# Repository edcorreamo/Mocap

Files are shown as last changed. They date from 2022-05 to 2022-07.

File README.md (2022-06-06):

## [ Esquemáticos ](https://github.com/edcorreamo/Mocap/tree/main/Esquematico)

En la presente sección va a encontrar el esquemático que se desarrollo para este proyecto ylas diferentes subsecciones que permiten conformar el circuito.

## [ Código ](https://github.com/JamesD004/MoCapUnal/tree/main/Imagenes)

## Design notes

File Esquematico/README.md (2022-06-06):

# Esquemático

## Esquema temporal

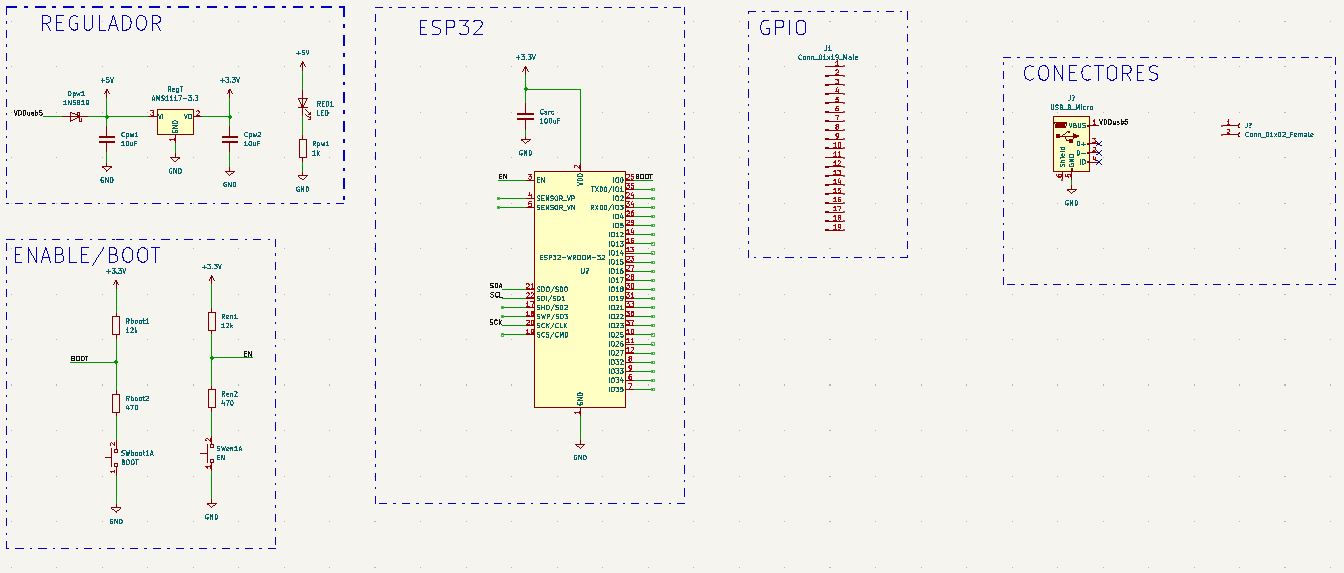
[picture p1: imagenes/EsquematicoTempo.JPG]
width=100


## Regulador
En esta seccion se encuentra el regulador de tensión buscando obtener una salida de 3.3V, para este proposito se hizo uso del regulador AMS1117. Por otro lado se implemento un diodo LED que ayuda a verificar el momento en el que el circuito se energice, el diodo schottky 1N5819 nos ayuda a asegurar que la tensión que pase por el regulador en la entrada V1 no se devuelva a la tension de entrada USB, finalmente los condensadores... . 

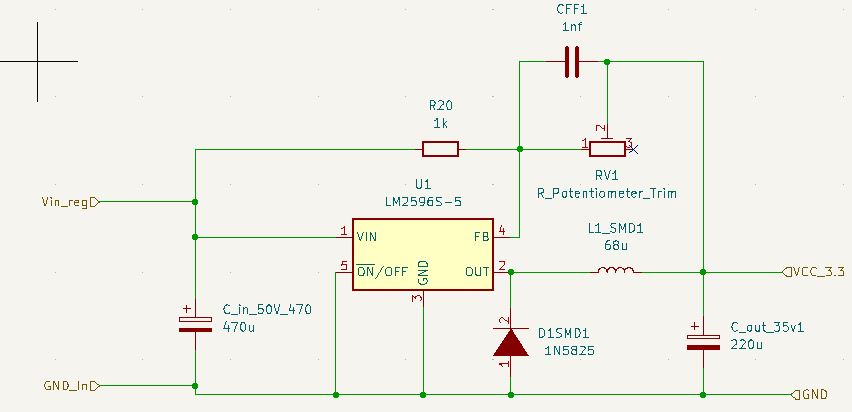
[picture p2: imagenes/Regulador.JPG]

A la salida del regulador se conecto un led que nos indica cuando el circuito se encuentre energizado, ya que la tensión de un led es de 1,6V y su corriente de peración es de 5mA la resistencia necesaria para su funcionamiento es de 330.

### LTspice
Con ayuda del IDE de LTspice diseñamos un pequeño cicuito y de este modo analizar la salida que se espera tener en este sistema, para este se usa un regulador LM317 con el cual se espera obtener un comportamiento similar con el AMS1117.

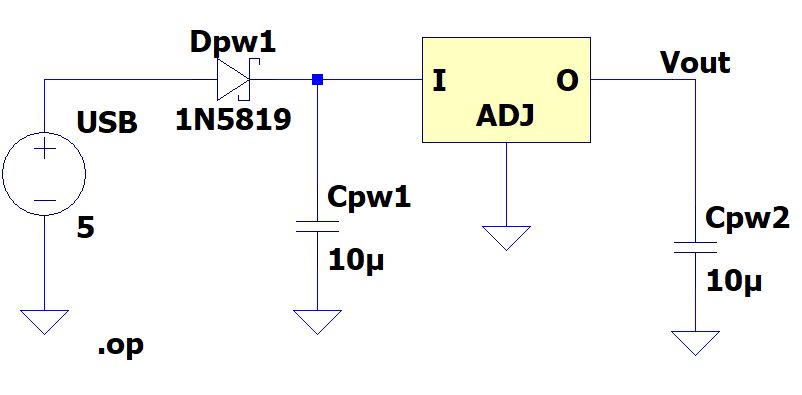
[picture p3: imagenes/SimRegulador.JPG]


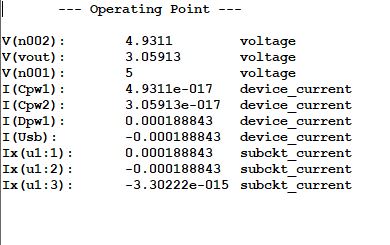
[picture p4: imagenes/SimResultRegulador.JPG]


## ENABLE/BOOT
La tensión en el enable y el boot en un caso ideal se considera con valores de 0 y 1, sin embargo esta se encuentra en un umbral de funcionamiento, en donde el valor de cero puede tomar hasta un valor de 0.124 mientras que para el funcionamiento del enable se tomo desde un valor de 0.7 el cual se va representar con ayuda de un diodo led.
### Ltspice
La tensión de caida de un diodo esta dado por 0.7V y la corriente en el led es de 5mA, por otro lado la corriente en el enable del ESP32 es de 264uA.
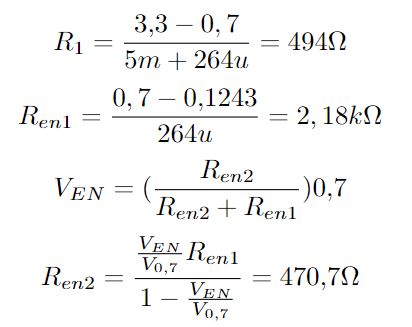
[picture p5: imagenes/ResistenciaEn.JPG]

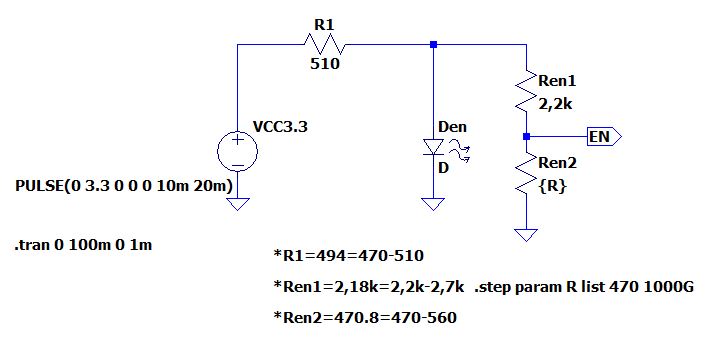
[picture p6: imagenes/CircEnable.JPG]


## ESP32


Para el desarrollo de este proyecto se hizo uso de un Soc ESP32-WROOM, debido a que representa una solucion ideal para suplir las necesidades de este proyecto. El Soc ESP32-WROOM entre otras cosas, posee un chip capaz de controlar multiplez sensores a la vez por medio de software y ademas cuenta tanto con modulo bluetooth como WIFI integrados, perimitiendo de esta manera la conxion inalambrica con otros dispositivos sin necesidad de un modulo complementario. 

Ahora, el proyecto se realizo teniendo en cuenta las condiciones de operacion y las limitaciones del ESP32-WROOM, este dispositivo debe ser alimentado idealmente con un voltaje de 3,3V o como maximo con un voltaje de 3,6V y puede entregar por sus pines de salida una corriente maxima de 1200mA. Ahora con respecto a sus diferesntes pines, la imagen anterior ilustra cada uno d ellos y sus particularidades.    

## Conectores

## USB

## MPU

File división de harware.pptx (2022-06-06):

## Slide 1

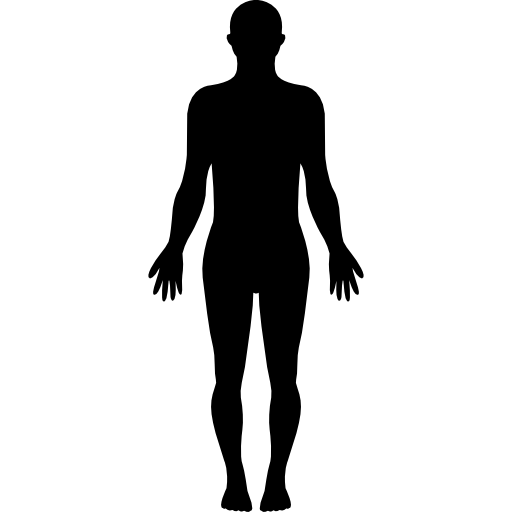
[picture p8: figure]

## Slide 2

1 sensor (sin bus)

1 bus + 1 sensor (pecho)

1 bus + 1 sensor bus

2 bus

2 bus (uno de ellos unido internamente al brazo)

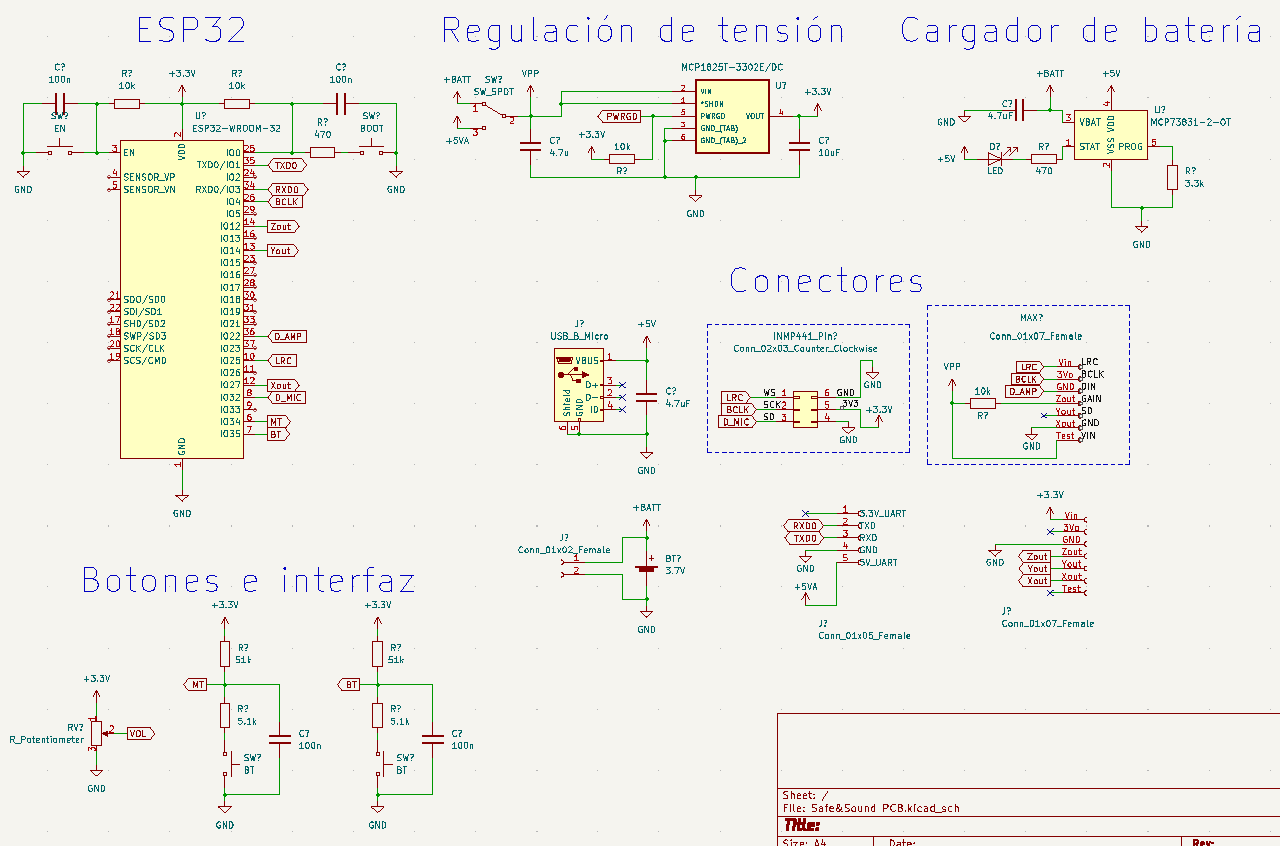
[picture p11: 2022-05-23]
copia de companeros.png

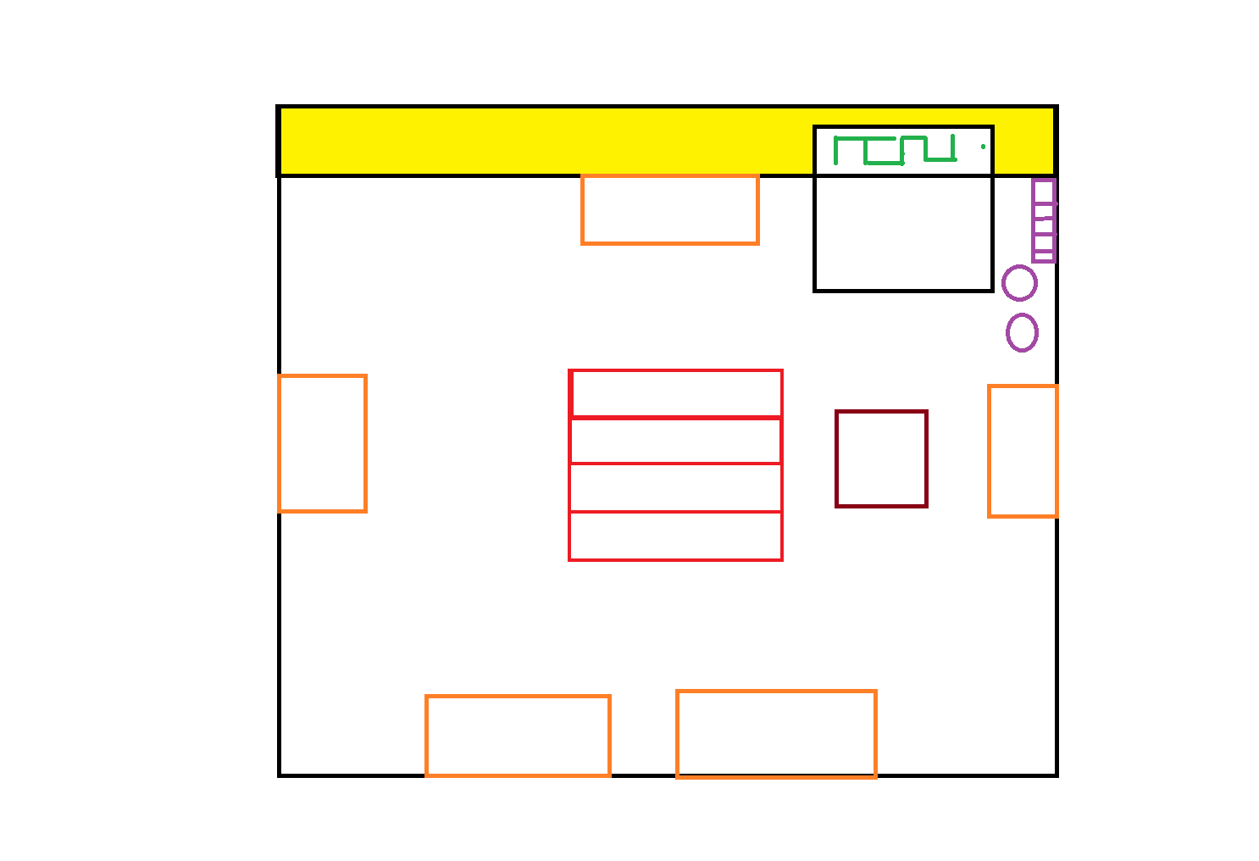
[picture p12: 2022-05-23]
posible ruteo.png

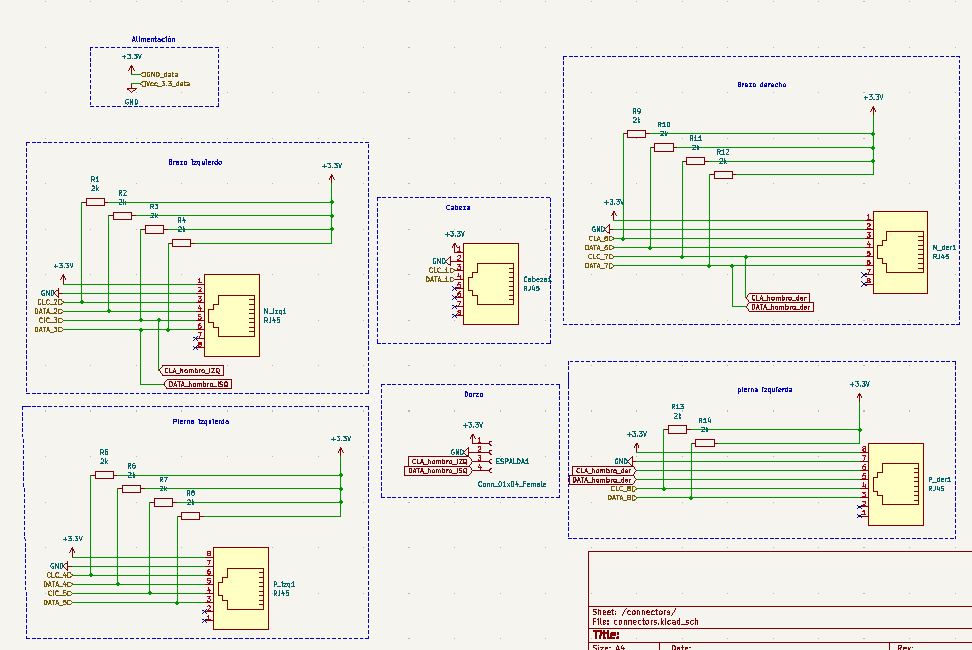
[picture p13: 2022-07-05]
imagenes/Conexiones.JPG

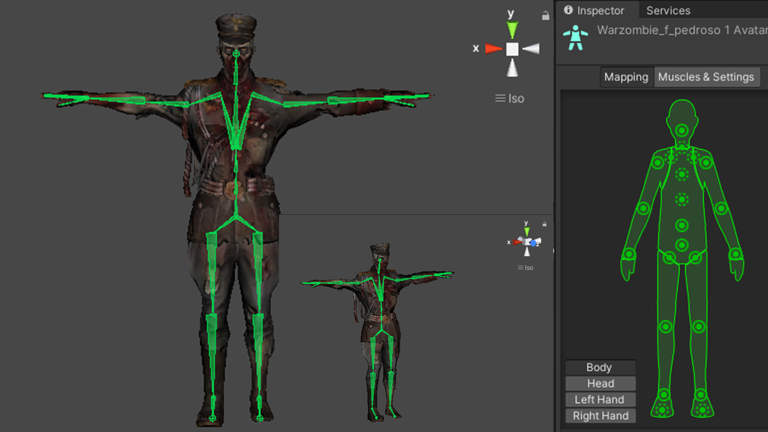
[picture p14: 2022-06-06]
imagenes/entornos_virtuales_2.png

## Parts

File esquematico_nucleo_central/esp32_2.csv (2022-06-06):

Source: | C:\Users\Prometeo\Documents\GitHub\Mocap\esquematico_nucleo_central\esp32_2.kicad_sch
Date: | 6/6/2022 11:11:27 AM
Tool: | Eeschema (6.0.1)
Generator: | C:\Program Files\KiCad\6.0\bin\scripting\plugins/bom_csv_grouped_by_value.py
Component Count: | 34
Individual Components:
Item | Qty | Reference(s) | Value | LibPart | Footprint | Datasheet | compra
 |  | Boot/flash1 | SW_Push | Switch:SW_Push | Button_Switch_SMD:SW_SPST_EVQQ2 | ~
 |  | C1 | 10u | Device:C | Capacitor_SMD:C_0805_2012Metric_Pad1.18x1.45mm_HandSolder | ~
 |  | C2 | 1nF/50V | Device:C | Capacitor_SMD:C_0805_2012Metric_Pad1.18x1.45mm_HandSolder | ~
 |  | C3 | 1nF/50V | Device:C | Capacitor_SMD:C_0805_2012Metric_Pad1.18x1.45mm_HandSolder | ~
 |  | C4 | 100u | Device:C | Capacitor_SMD:C_0805_2012Metric_Pad1.18x1.45mm_HandSolder | ~
 |  | C_in_50V_470 | 470u | Device:C_Polarized | Capacitor_SMD:CP_Elec_8x6.9 | ~
 |  | C_out_35v1 | 220u | Device:C_Polarized | Capacitor_SMD:CP_Elec_8x6.9 | ~
 |  | Cabeza1 | RJ45 | Connector:RJ45 | Connector_RJ:RJ45_Amphenol_54602-x08_Horizontal | ~
 |  | CFF1 | 1nf | Device:C | Capacitor_SMD:C_0805_2012Metric_Pad1.18x1.45mm_HandSolder | ~
 |  | Control_voltaje1 | Conn_01x02_Male | Connector:Conn_01x02_Male | Connector_PinHeader_2.54mm:PinHeader_1x02_P2.54mm_Vertical | ~
 |  | D1 | LED | Device:LED | LED_SMD:LED_1206_3216Metric_Pad1.42x1.75mm_HandSolder | ~
 |  | D1SMD1 | 1N5825 | pspice:DIODE | Diode_SMD:D_3220_8050Metric_Pad2.65x5.15mm_HandSolder | ~
 |  | D2 | LED | Device:LED | LED_SMD:LED_1206_3216Metric_Pad1.42x1.75mm_HandSolder | ~ | https://articulo.mercadolibre.com.co/MCO-638946948-diodo-led-smd-1206-x-5-unidades-_JM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
 |  | D3 | LED | Device:LED | LED_SMD:LED_1206_3216Metric_Pad1.42x1.75mm_HandSolder | ~ | https://articulo.mercadolibre.com.co/MCO-638946948-diodo-led-smd-1206-x-5-unidades-_JM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
 |  | ESP32 | ESP32-WROOM-32 | RF_Module:ESP32-WROOM-32 | RF_Module:ESP32-WROOM-32 | https://www.espressif.com/sites/default/files/documentation/esp32-wroom-32_datasheet_en.pdf
 |  | Espalda1 | Conn_01x08_Male | Connector:Conn_01x08_Male | Connector_PinHeader_2.54mm:PinHeader_1x08_P2.54mm_Vertical | ~
 |  | L1_SMD1 | 68u | Device:L | Inductor_SMD:L_Wuerth_HCM-1390 | ~
 |  | M_der1 | RJ45 | Connector:RJ45 | Connector_RJ:RJ45_Amphenol_54602-x08_Horizontal | ~
 |  | M_izq1 | RJ45 | Connector:RJ45 | Connector_RJ:RJ45_Amphenol_54602-x08_Horizontal | ~
 |  | N_batt1 | Conn_01x01_Female | Connector:Conn_01x01_Female | Connector_PinHeader_2.54mm:PinHeader_1x01_P2.54mm_Vertical | ~
 |  | P_Batt1 | Conn_01x01_Female | Connector:Conn_01x01_Female | Connector_PinHeader_2.54mm:PinHeader_1x01_P2.54mm_Vertical | ~
 |  | P_der1 | RJ45 | Connector:RJ45 | Connector_RJ:RJ45_Amphenol_54602-x08_Horizontal | ~
 |  | P_izq1 | RJ45 | Connector:RJ45 | Connector_RJ:RJ45_Amphenol_54602-x08_Horizontal | ~
 |  | Programador1 | Programador | Connector:Conn_01x05_Female | Connector_PinHeader_2.54mm:PinHeader_1x05_P2.54mm_Vertical | ~
 |  | R15 | 10k | Device:R | Resistor_SMD:R_0805_2012Metric_Pad1.20x1.40mm_HandSolder | ~
 |  | R16 | 10k | Device:R | Resistor_SMD:R_0805_2012Metric_Pad1.20x1.40mm_HandSolder | ~
 |  | R17 | 10k | Device:R | Resistor_SMD:R_0805_2012Metric_Pad1.20x1.40mm_HandSolder | ~
 |  | R18 | 10k | Device:R | Resistor_SMD:R_0805_2012Metric_Pad1.20x1.40mm_HandSolder | ~
 |  | R19 | 10k | Device:R | Resistor_SMD:R_0805_2012Metric_Pad1.20x1.40mm_HandSolder | ~
 |  | R20 | 1k | Device:R | Resistor_SMD:R_0805_2012Metric_Pad1.20x1.40mm_HandSolder | ~
 |  | Reset1 | SW_Push | Switch:SW_Push | Button_Switch_SMD:SW_SPST_EVQQ2 | ~
 |  | RV1 | R_Potentiometer_Trim | Device:R_Potentiometer_Trim | Potentiometer_THT:Potentiometer_Bourns_3296W_Vertical | ~
 |  | SW1 | SW_DIP_x01 | Switch:SW_DIP_x01 | Button_Switch_THT:SW_DIP_SPSTx01_Slide_9.78x4.72mm_W7.62mm_P2.54mm | ~
 |  | U1 | LM2596S-5 | Regulator_Switching:LM2596S-5 | Package_TO_SOT_SMD:TO-263-5_TabPin3 | http://www.ti.com/lit/ds/symlink/lm2596.pdf
Collated Components:
Item | Qty | Reference(s) | Value | LibPart | Footprint | Datasheet | compra
1 | 2 | Boot/flash1, Reset1 | SW_Push | Switch:SW_Push | Button_Switch_SMD:SW_SPST_EVQQ2 | ~
2 | 1 | C1 | 10u | Device:C | Capacitor_SMD:C_0805_2012Metric_Pad1.18x1.45mm_HandSolder | ~
3 | 2 | C2, C3 | 1nF/50V | Device:C | Capacitor_SMD:C_0805_2012Metric_Pad1.18x1.45mm_HandSolder | ~
4 | 1 | C4 | 100u | Device:C | Capacitor_SMD:C_0805_2012Metric_Pad1.18x1.45mm_HandSolder | ~
5 | 1 | C_in_50V_470 | 470u | Device:C_Polarized | Capacitor_SMD:CP_Elec_8x6.9 | ~
6 | 1 | C_out_35v1 | 220u | Device:C_Polarized | Capacitor_SMD:CP_Elec_8x6.9 | ~
7 | 5 | Cabeza1, M_der1, M_izq1, P_der1, P_izq1 | RJ45 | Connector:RJ45 | Connector_RJ:RJ45_Amphenol_54602-x08_Horizontal | ~
8 | 1 | CFF1 | 1nf | Device:C | Capacitor_SMD:C_0805_2012Metric_Pad1.18x1.45mm_HandSolder | ~
9 | 1 | Control_voltaje1 | Conn_01x02_Male | Connector:Conn_01x02_Male | Connector_PinHeader_2.54mm:PinHeader_1x02_P2.54mm_Vertical | ~
10 | 3 | D1, D2, D3 | LED | Device:LED | LED_SMD:LED_1206_3216Metric_Pad1.42x1.75mm_HandSolder | ~ | https://articulo.mercadolibre.com.co/MCO-638946948-diodo-led-smd-1206-x-5-unidades-_JM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
11 | 1 | D1SMD1 | 1N5825 | pspice:DIODE | Diode_SMD:D_3220_8050Metric_Pad2.65x5.15mm_HandSolder | ~
12 | 1 | ESP32 | ESP32-WROOM-32 | RF_Module:ESP32-WROOM-32 | RF_Module:ESP32-WROOM-32 | https://www.espressif.com/sites/default/files/documentation/esp32-wroom-32_datasheet_en.pdf
13 | 1 | Espalda1 | Conn_01x08_Male | Connector:Conn_01x08_Male | Connector_PinHeader_2.54mm:PinHeader_1x08_P2.54mm_Vertical | ~
14 | 1 | L1_SMD1 | 68u | Device:L | Inductor_SMD:L_Wuerth_HCM-1390 | ~
15 | 2 | N_batt1, P_Batt1 | Conn_01x01_Female | Connector:Conn_01x01_Female | Connector_PinHeader_2.54mm:PinHeader_1x01_P2.54mm_Vertical | ~
16 | 1 | Programador1 | Programador | Connector:Conn_01x05_Female | Connector_PinHeader_2.54mm:PinHeader_1x05_P2.54mm_Vertical | ~
17 | 5 | R15, R16, R17, R18, R19 | 10k | Device:R | Resistor_SMD:R_0805_2012Metric_Pad1.20x1.40mm_HandSolder | ~
18 | 1 | R20 | 1k | Device:R | Resistor_SMD:R_0805_2012Metric_Pad1.20x1.40mm_HandSolder | ~
19 | 1 | RV1 | R_Potentiometer_Trim | Device:R_Potentiometer_Trim | Potentiometer_THT:Potentiometer_Bourns_3296W_Vertical | ~
20 | 1 | SW1 | SW_DIP_x01 | Switch:SW_DIP_x01 | Button_Switch_THT:SW_DIP_SPSTx01_Slide_9.78x4.72mm_W7.62mm_P2.54mm | ~
21 | 1 | U1 | LM2596S-5 | Regulator_Switching:LM2596S-5 | Package_TO_SOT_SMD:TO-263-5_TabPin3 | http://www.ti.com/lit/ds/symlink/lm2596.pdf

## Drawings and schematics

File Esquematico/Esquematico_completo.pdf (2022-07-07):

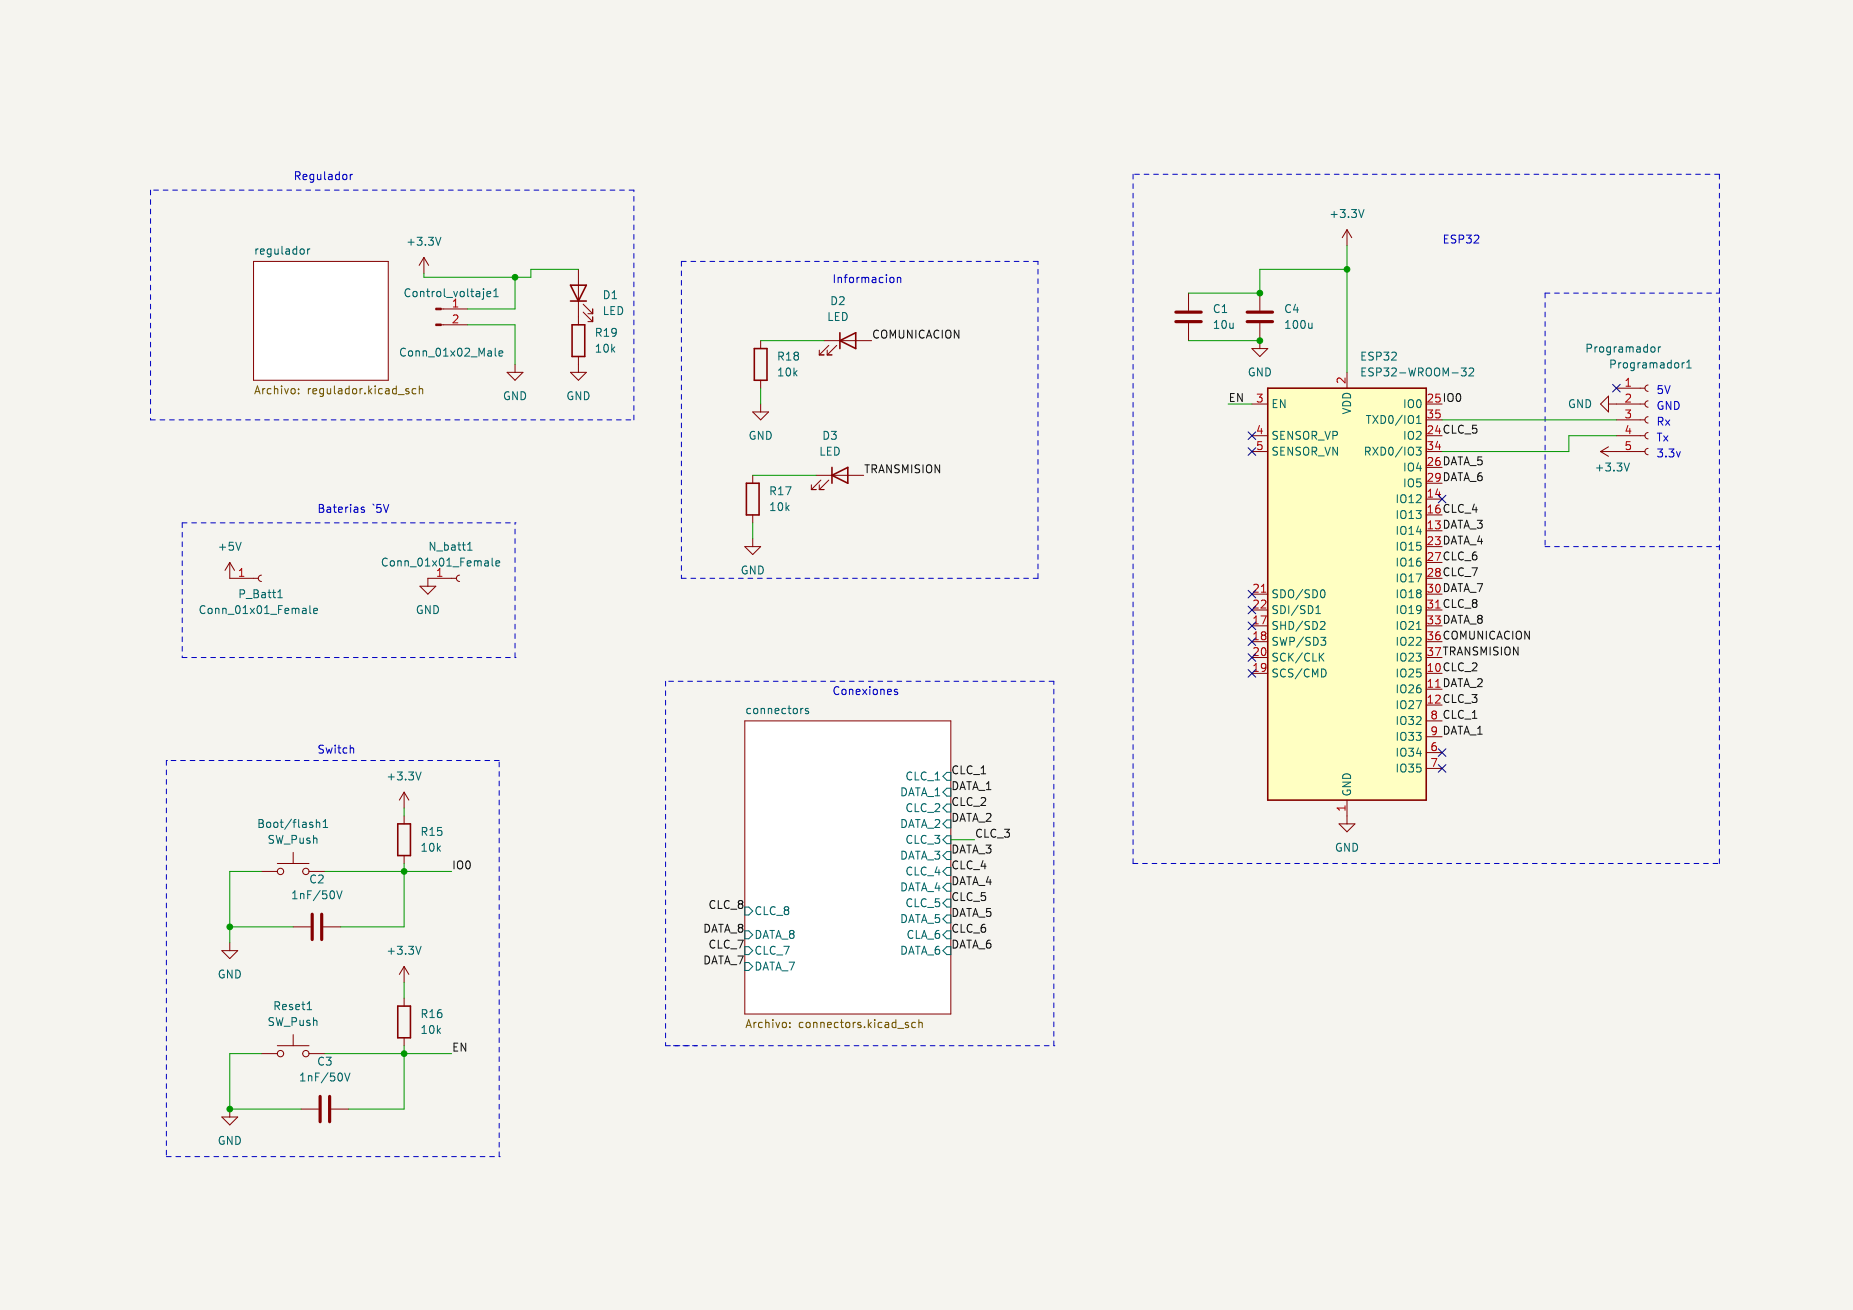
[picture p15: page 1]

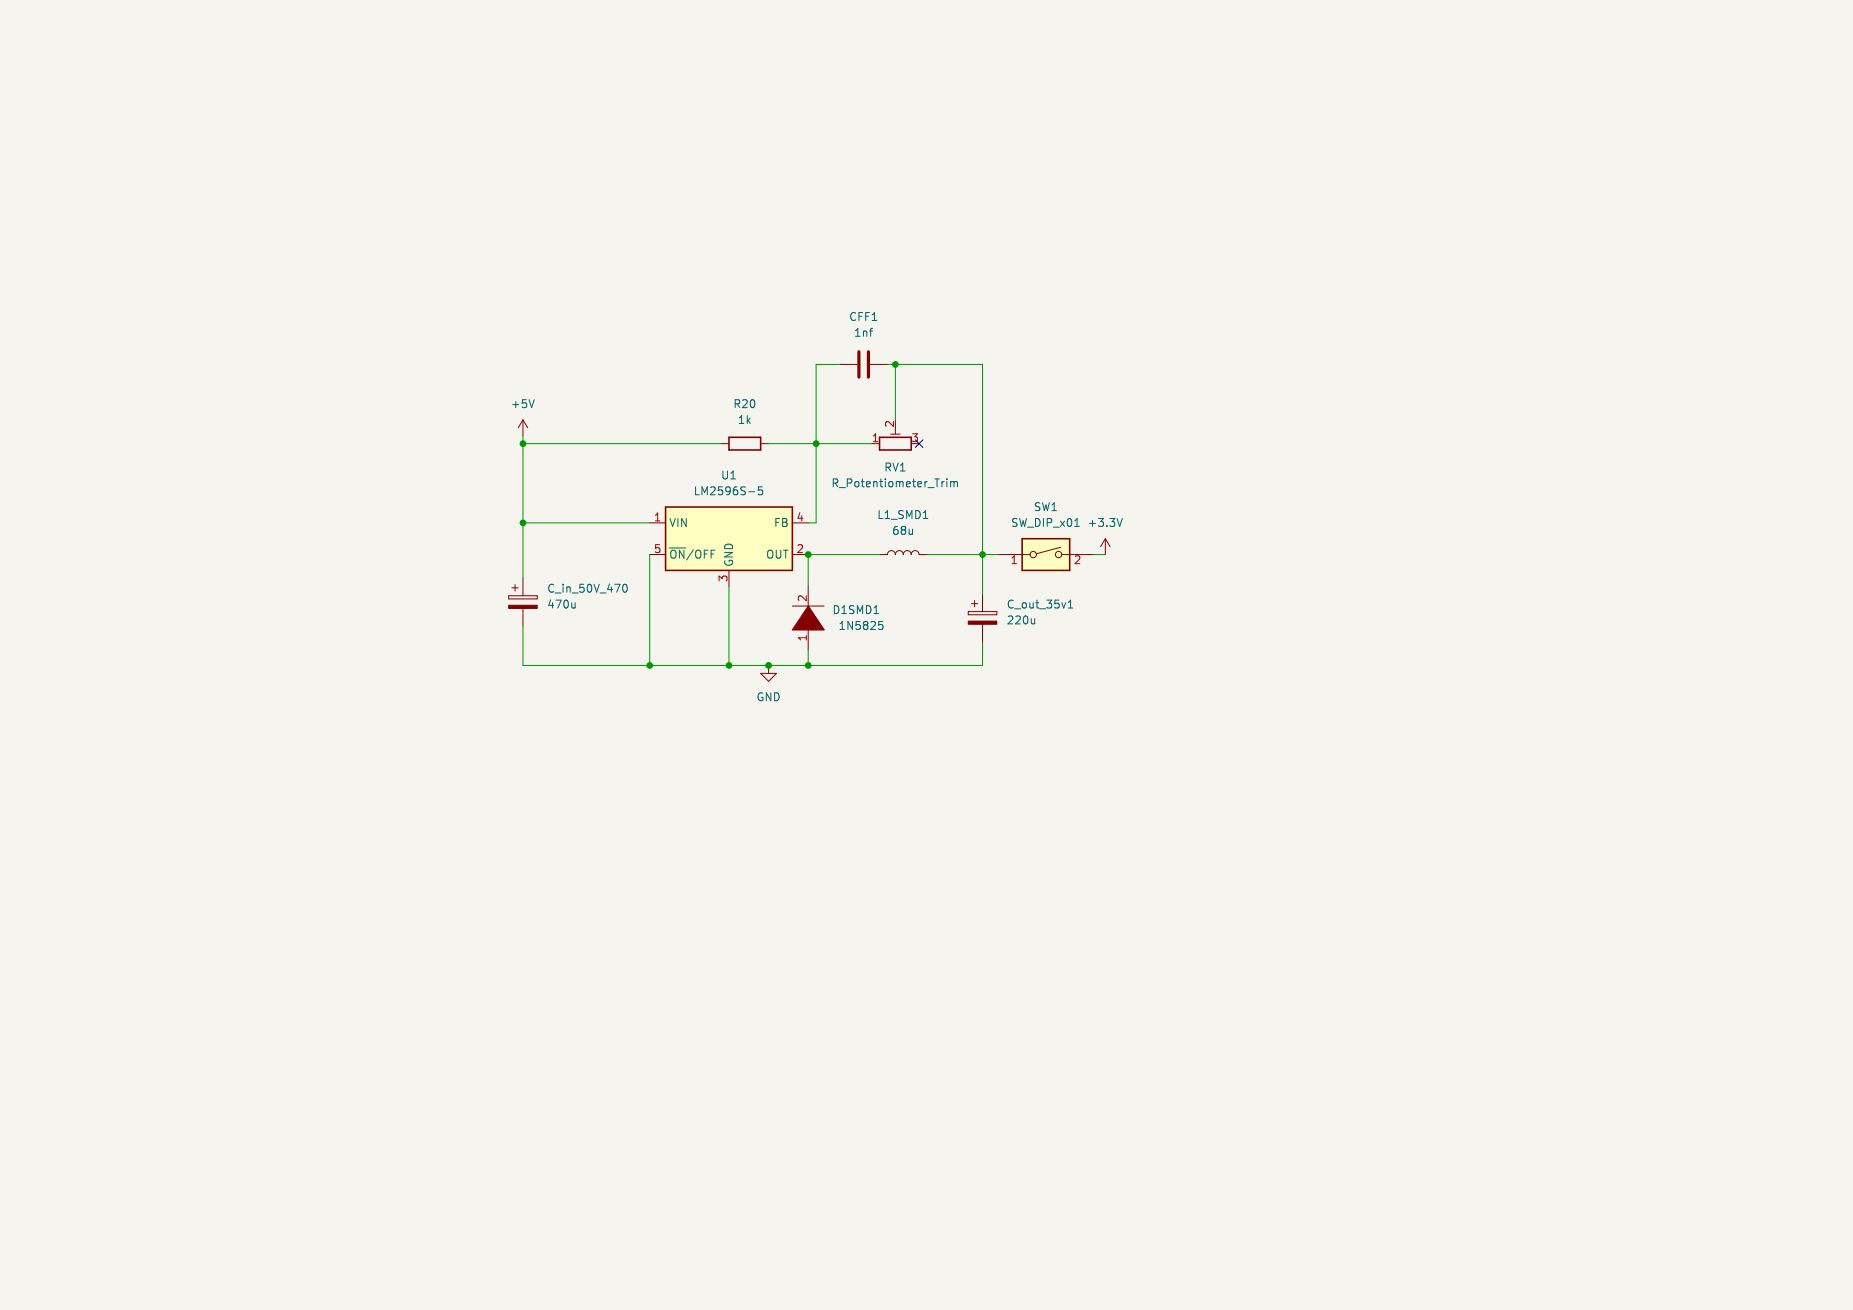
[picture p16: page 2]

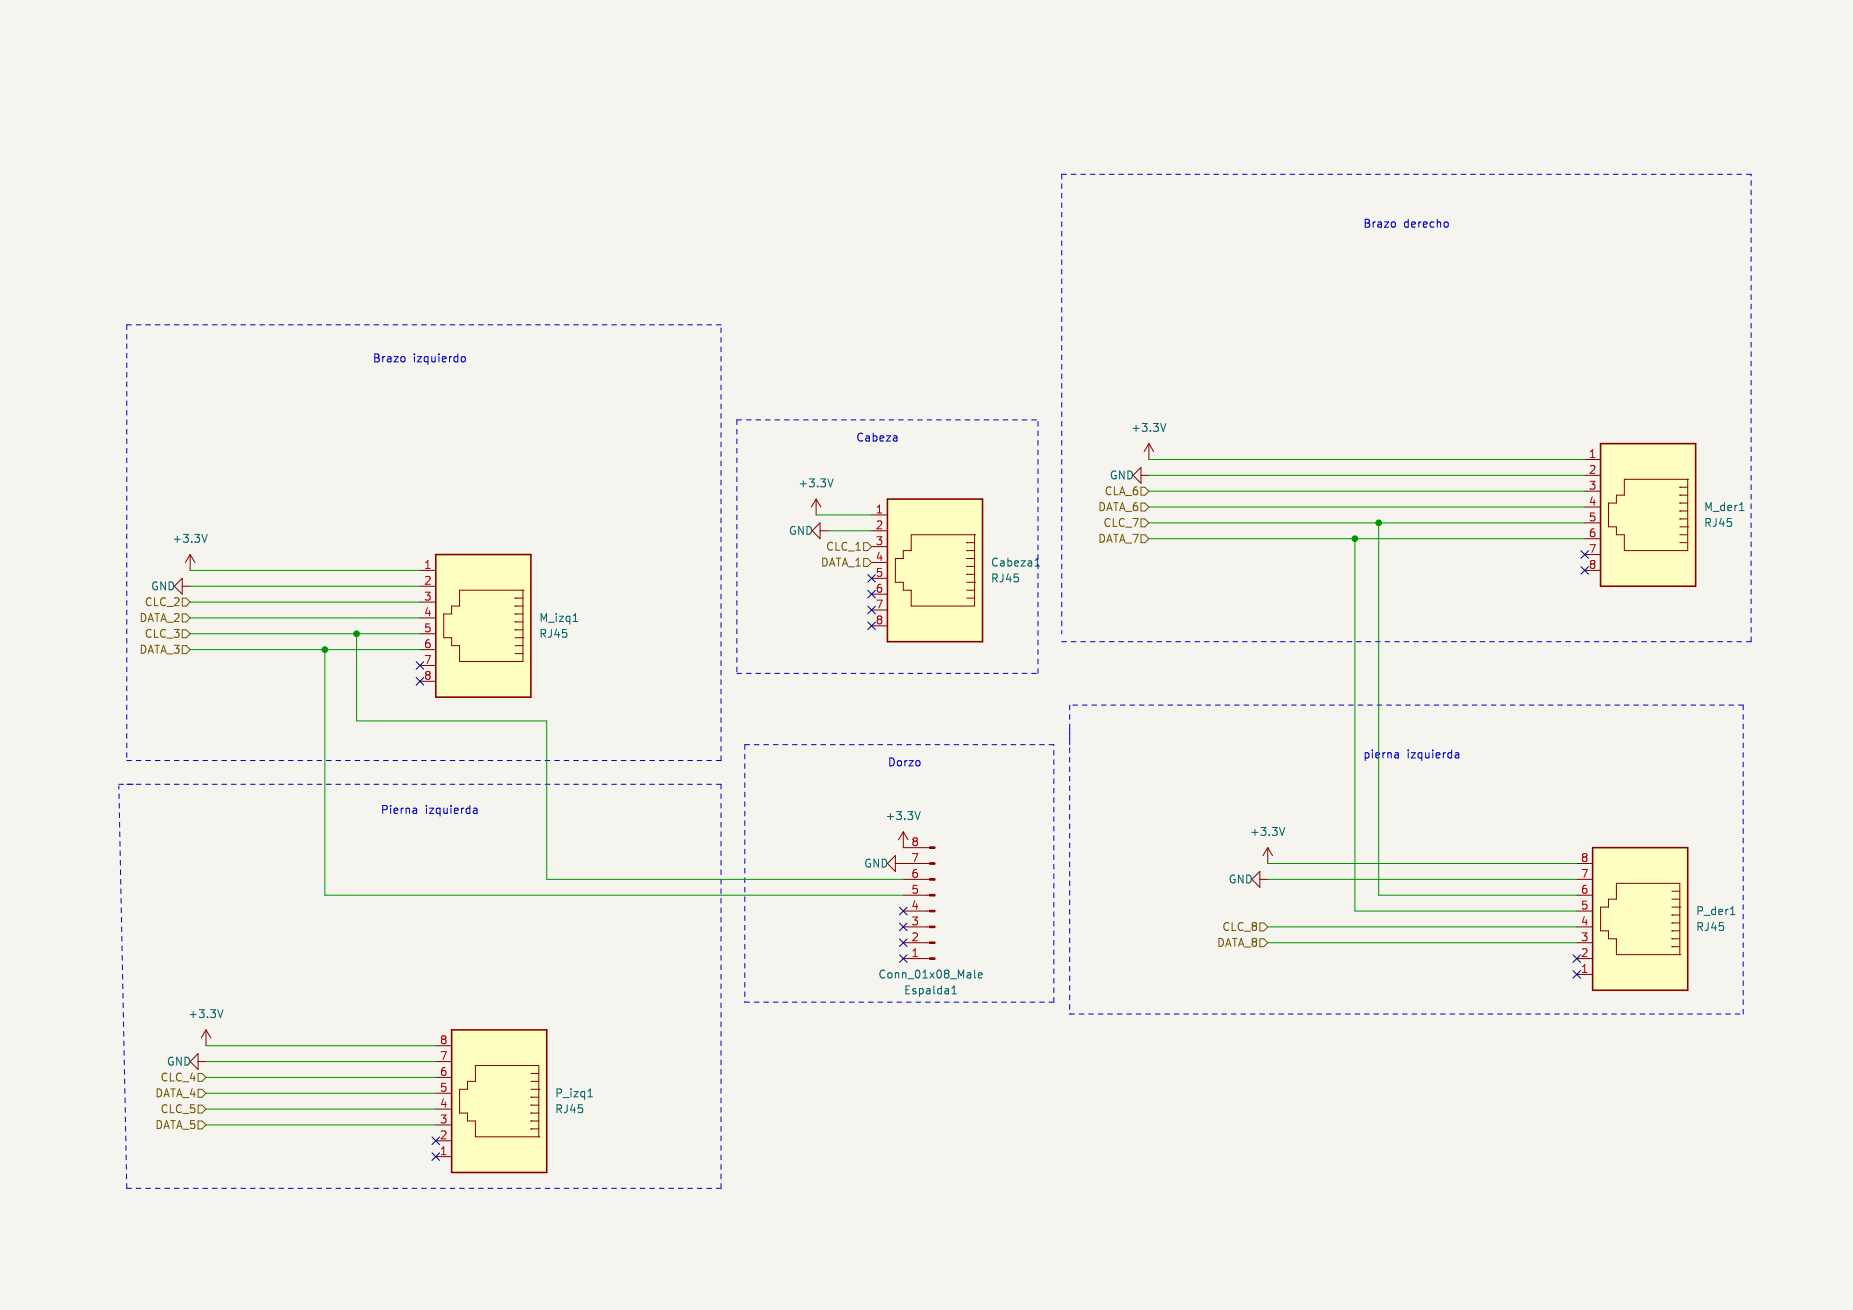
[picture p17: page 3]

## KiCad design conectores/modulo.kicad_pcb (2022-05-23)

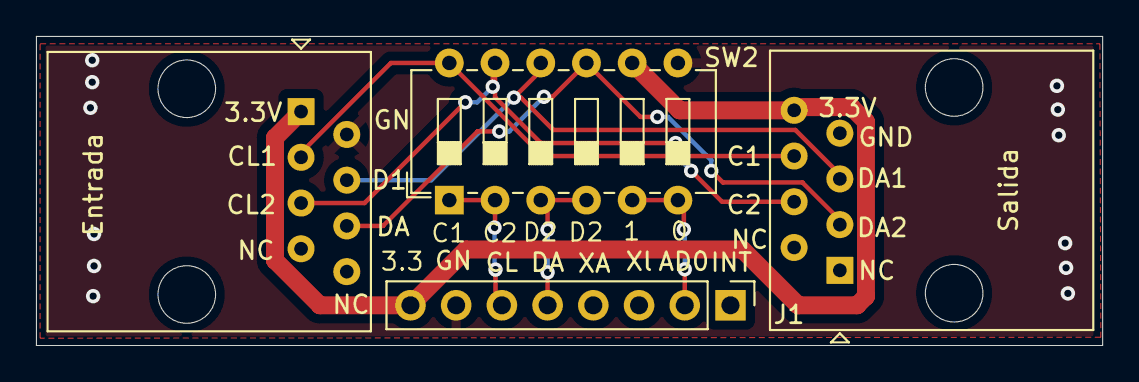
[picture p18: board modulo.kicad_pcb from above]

Board: 2 copper layers, 59.2 x 17.2 mm, 4 parts (0 on the bottom side), 9 nets.

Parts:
Entrada: RJ45; RJ45_Amphenol_54602-x08_Horizontal
J1: Conn_01x08_Female; PinHeader_1x08_P2.54mm_Vertical
SW2: SW_DIP_x06; SW_DIP_SPSTx06_Slide_6.7x16.8mm_W7.62mm_P2.54mm_LowProfile
Salida: RJ45; RJ45_Amphenol_54602-x08_Horizontal

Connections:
+3V3: Entrada.1, J1.8, SW2.8, Salida.8
GND: Entrada.2, J1.7, SW2.7, Salida.7
unnamed: Entrada.3, SW2.12, Salida.6
unnamed: Entrada.4, SW2.10, Salida.5
unnamed: Entrada.5, SW2.11, Salida.4
unnamed: Entrada.6, SW2.9, Salida.3
unnamed: J1.2, SW2.5, SW2.6
unnamed: J1.5, SW2.3, SW2.4
unnamed: J1.6, SW2.1, SW2.2

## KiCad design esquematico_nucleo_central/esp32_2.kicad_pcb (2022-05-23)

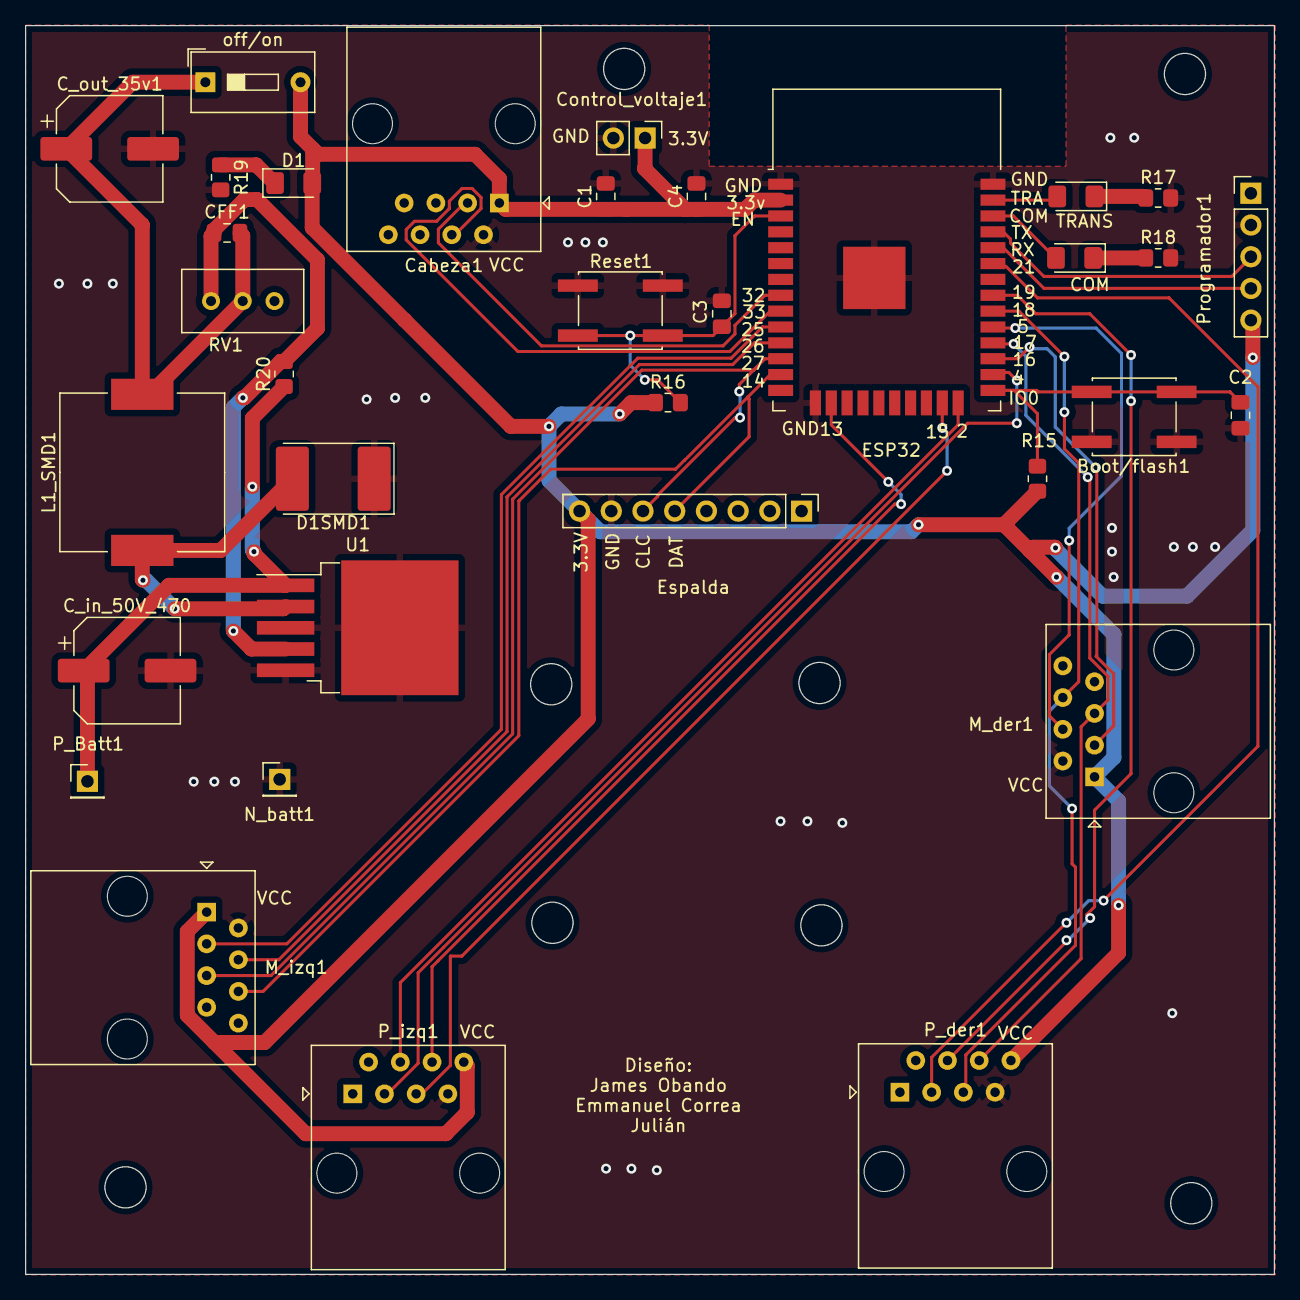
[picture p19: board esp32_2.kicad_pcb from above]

Board: 2 copper layers, 100.0 x 100.0 mm, 34 parts (0 on the bottom side), 31 nets.

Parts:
Boot/flash1: SW_Push; SW_SPST_EVQQ2
C1: 10u; C_0805_2012Metric_Pad1.18x1.45mm_HandSolder
C2, C3: 1nF/50V; C_0805_2012Metric_Pad1.18x1.45mm_HandSolder
C4: 100u; C_0805_2012Metric_Pad1.18x1.45mm_HandSolder
CFF1: 1nf; C_0805_2012Metric_Pad1.18x1.45mm_HandSolder
COM: LED; LED_1206_3216Metric_Pad1.42x1.75mm_HandSolder
C_in_50V_470: 470u; CP_Elec_8x6.9
C_out_35v1: 220u; CP_Elec_8x6.9
Cabeza1: RJ45; RJ45_Amphenol_54602-x08_Horizontal
Control_voltaje1: Conn_01x02_Male; PinHeader_1x02_P2.54mm_Vertical
D1: LED; LED_1206_3216Metric_Pad1.42x1.75mm_HandSolder
D1SMD1: 1N5825; D_3220_8050Metric_Pad2.65x5.15mm_HandSolder
ESP32: ESP32-WROOM-32
Espalda: Conn_01x08_Male; PinHeader_1x08_P2.54mm_Vertical
L1_SMD1: 68u; L_Wuerth_HCM-1390
M_der1: RJ45; RJ45_Amphenol_54602-x08_Horizontal
M_izq1: RJ45; RJ45_Amphenol_54602-x08_Horizontal
N_batt1: Conn_01x01_Female; PinHeader_1x01_P2.54mm_Vertical
P_Batt1: Conn_01x01_Female; PinHeader_1x01_P2.54mm_Vertical
P_der1: RJ45; RJ45_Amphenol_54602-x08_Horizontal
P_izq1: RJ45; RJ45_Amphenol_54602-x08_Horizontal
Programador1: Programador; PinHeader_1x05_P2.54mm_Vertical
R15, R16, R17, R18, R19: 10k; R_0805_2012Metric_Pad1.20x1.40mm_HandSolder
R20: 1k; R_0805_2012Metric_Pad1.20x1.40mm_HandSolder
RV1: R_Potentiometer_Trim; Potentiometer_Bourns_3296W_Vertical
Reset1: SW_Push; SW_SPST_EVQQ2
TRANS: LED; LED_1206_3216Metric_Pad1.42x1.75mm_HandSolder
U1: LM2596S-5; TO-263-5_TabPin3
off/on: SW_DIP_x01; SW_DIP_SPSTx01_Slide_9.78x4.72mm_W7.62mm_P2.54mm

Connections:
+3V3: C1.1, C4.1, Cabeza1.1, Control_voltaje1.1, D1.2 (A), ESP32.2 (VDD), Espalda.8, M_der1.1, M_izq1.1, P_der1.8, P_izq1.8, Programador1.5, R15.1, R16.1, off/on.2
+5V: C_in_50V_470.1, P_Batt1.1, R20.1, U1.1 (VIN)
/CLC_1: Cabeza1.3, ESP32.8 (IO32)
/CLC_2: ESP32.10 (IO25), M_izq1.3
/CLC_3: ESP32.12 (IO27), Espalda.6, M_izq1.5
/CLC_4: ESP32.16 (IO13), P_izq1.6
/CLC_5: ESP32.24 (IO2), P_izq1.4
/CLC_6: ESP32.27 (IO16), M_der1.3
/CLC_7: ESP32.28 (IO17), M_der1.5, P_der1.6
/CLC_8: ESP32.31 (IO19), P_der1.4
/COMUNICACION: COM.2 (A), ESP32.36 (IO22)
/DATA_1: Cabeza1.4, ESP32.9 (IO33)
/DATA_2: ESP32.11 (IO26), M_izq1.4
/DATA_3: ESP32.13 (IO14), Espalda.5, M_izq1.6
/DATA_4: ESP32.23 (IO15), P_izq1.5
/DATA_5: ESP32.26 (IO4), P_izq1.3
/DATA_6: ESP32.29 (IO5), M_der1.4
/DATA_7: ESP32.30 (IO18), M_der1.6, P_der1.5
/DATA_8: ESP32.33 (IO21), P_der1.3
/EN: C3.2, ESP32.3 (EN), R16.2, Reset1.2
/IO0: Boot/flash1.2, C2.2, ESP32.25 (IO0), R15.2
/TRANSMISION: ESP32.37 (IO23), TRANS.2 (A)
GND: Boot/flash1.1, C1.2, C2.1, C3.1, C4.2, C_in_50V_470.2, C_out_35v1.2, Cabeza1.2, Control_voltaje1.2, D1SMD1.1 (K), ESP32.1 (GND), ESP32.15 (GND), ESP32.38 (GND), ESP32.39 (GND), Espalda.7, M_der1.2, M_izq1.2, N_batt1.1, P_der1.7, P_izq1.7, Programador1.2, R17.2, R18.2, R19.2, Reset1.1, U1.3 (GND), U1.5 (~ON/OFF)
unnamed: CFF1.1, R20.2, RV1.1, U1.4 (FB)
unnamed: CFF1.2, C_out_35v1.1, L1_SMD1.2, RV1.2, off/on.1
unnamed: D1.1 (K), R19.1
unnamed: D1SMD1.2 (A), L1_SMD1.1, U1.2 (OUT)
unnamed: COM.1 (K), R18.1
unnamed: R17.1, TRANS.1 (K)
unnamed: ESP32.34 (RXD0/IO3), Programador1.4
unnamed: ESP32.35 (TXD0/IO1), Programador1.3

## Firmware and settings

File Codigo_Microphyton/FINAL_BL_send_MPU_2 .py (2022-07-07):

from machine import SoftI2C
from machine import I2C
from machine import Pin
from machine import sleep
import mpu6050

##FUNCIONA###

import bluetooth
from ble_advertising import advertising_payload
import ble_uart_peripheral

from micropython import const
import time
addr=0x68

ble = bluetooth.BLE()
uart = ble_uart_peripheral.BLEUART(ble)

def on_rx():
    print("rx: ", uart.read().decode().strip())

uart.irq(handler=on_rx)

try:
    while True:
        if addr==0x68:
            #Mder_1
            i2c11 = SoftI2C(scl=Pin(16), sda=Pin(5))     #initializing the I2C method for ESP32
            mpu11= mpu6050.accel(i2c11,addr)
            AC11=mpu11.get_values()
            print(str(AC11[1]),str(AC11[2]),str(AC11[3]),'i2c11')
            uart.write(str(AC11[1]) + str(AC11[2])+ str(AC11[3])+ 'i2c11' +"\n")
            #P_der1
#             i2c21 = SoftI2C(scl=Pin(17), sda=Pin(18))     #initializing the I2C method for ESP32
#             mpu21= mpu6050.accel(i2c21,addr)
#             AC21=mpu21.get_values()
#             print(str(AC21[1]),str(AC21[2]),str(AC21[3]),'i2c21')
#             uart.write(str(AC21[1]) + str(AC21[2])+ str(AC21[3])+ 'i2c21' +"\n")
# # 
            i2c31 = SoftI2C(scl=Pin(13), sda=Pin(15))     #initializing the I2C method for ESP32
            mpu31= mpu6050.accel(i2c31,addr)
            AC31=mpu31.get_values()
            print(str(AC31[1]),str(AC31[2]),str(AC31[3]),'i2c31')
            uart.write(str(AC31[1]) + str(AC31[2])+ str(AC31[3])+ 'i2c31' +"\n")
            
            i2c41 = SoftI2C(scl=Pin(2), sda=Pin(4))     #initializing the I2C method for ESP32
            mpu41= mpu6050.accel(i2c41,addr)
            AC41=mpu41.get_values()
            print(str(AC41[1]),str(AC41[2]),str(AC41[3]),'i2c41')
            uart.write(str(AC41[1]) + str(AC41[2])+ str(AC41[3])+ 'i2c41' +"\n")
            
            i2c51 = SoftI2C(scl=Pin(25), sda=Pin(26))     #initializing the I2C method for ESP32
            mpu51= mpu6050.accel(i2c51,addr)
            AC51=mpu51.get_values()
            print(str(AC51[1]),str(AC51[2]),str(AC51[3]),'i2c51')
            uart.write(str(AC51[1]) + str(AC51[2])+ str(AC51[3])+ 'i2c51' +"\n")
            
            i2c61 = SoftI2C(scl=Pin(27), sda=Pin(14))     #initializing the I2C method for ESP32
            mpu61= mpu6050.accel(i2c61,addr)
            AC61=mpu61.get_values()
            print(str(AC61[1]),str(AC61[2]),str(AC61[3]),'i2c61')
            uart.write(str(AC61[1]) + str(AC61[2])+ str(AC61[3])+ 'i2c61' +"\n")
          
            i2c71 = SoftI2C(scl=Pin(32), sda=Pin(33))     #initializing the I2C method for ESP32
            mpu71= mpu6050.accel(i2c71,addr)
            AC71=mpu71.get_values()
            print(str(AC71[1]),str(AC71[2]),str(AC71[3]),'i2c71')
            uart.write(str(AC71[1]) + str(AC71[2])+ str(AC71[3])+ 'i2c71' +"\n")
          
            
            
            addr=0x69;
        
        else:
            #M_der1
            i2c12 = SoftI2C(scl=Pin(16), sda=Pin(5))     #initializing the I2C method for ESP32
            mpu12= mpu6050.accel(i2c12,addr)
            AC12=mpu11.get_values()
            print(str(AC12[1]),str(AC12[2]),str(AC12[3]),'i2c12')
            uart.write(str(AC12[1]) + str(AC12[2])+ str(AC12[3])+ 'i2c12' +"\n")
            #P_der1
            
#             i2c22 = SoftI2C(scl=Pin(17), sda=Pin(18))     #initializing the I2C method for ESP32
#             mpu22= mpu6050.accel(i2c22,addr)
#             AC22=mpu21.get_values()
#             print(str(AC22[1]),str(AC22[2]),str(AC22[3]),'i2c22')
#             uart.write(str(AC22[1]) + str(AC22[2])+ str(AC22[3])+ 'i2c22' +"\n")

            i2c32 = SoftI2C(scl=Pin(13), sda=Pin(15))     #initializing the I2C method for ESP32
            mpu32= mpu6050.accel(i2c32,addr)
            AC32=mpu32.get_values()
            print(str(AC32[1]),str(AC32[2]),str(AC32[3]),'i2c32')
            uart.write(str(AC32[1]) + str(AC32[2])+ str(AC32[3])+ 'i2c32' +"\n")
            
            i2c42 = SoftI2C(scl=Pin(2), sda=Pin(4))     #initializing the I2C method for ESP32
            mpu42= mpu6050.accel(i2c42,addr)
            AC42=mpu42.get_values()
            print(str(AC42[1]),str(AC42[2]),str(AC42[3]),'i2c42')
            uart.write(str(AC42[1]) + str(AC42[2])+ str(AC42[3])+ 'i2c42' +"\n")
            
            i2c52 = SoftI2C(scl=Pin(25), sda=Pin(26))     #initializing the I2C method for ESP32
            mpu52= mpu6050.accel(i2c51,addr)
            AC52=mpu52.get_values()
            print(str(AC52[1]),str(AC52[2]),str(AC52[3]),'i2c52')
            uart.write(str(AC52[1]) + str(AC52[2])+ str(AC52[3])+ 'i2c52' +"\n")
            
            i2c62 = SoftI2C(scl=Pin(27), sda=Pin(14))     #initializing the I2C method for ESP32
            mpu62= mpu6050.accel(i2c62,addr)
            AC62=mpu62.get_values()
            print(str(AC62[1]),str(AC62[2]),str(AC62[3]),'i2c62')
            uart.write(str(AC62[1]) + str(AC62[2])+ str(AC62[3])+ 'i2c62' +"\n")
            
#             
#             
            addr=0x68;
            
        #########33#############3
        ######################

        
        
        time.sleep_ms(100)

except KeyboardInterrupt:
    pass

uart.close()

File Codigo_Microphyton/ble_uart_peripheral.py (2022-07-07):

# This example demonstrates a peripheral implementing the Nordic UART Service (NUS).

import bluetooth
from ble_advertising import advertising_payload

from micropython import const

_IRQ_CENTRAL_CONNECT = const(1)
_IRQ_CENTRAL_DISCONNECT = const(2)
_IRQ_GATTS_WRITE = const(3)

_FLAG_WRITE = const(0x0008)
_FLAG_NOTIFY = const(0x0010)

_UART_UUID = bluetooth.UUID("6E400001-B5A3-F393-E0A9-E50E24DCCA9E")
_UART_TX = (
    bluetooth.UUID("6E400003-B5A3-F393-E0A9-E50E24DCCA9E"),
    _FLAG_NOTIFY,
)
_UART_RX = (
    bluetooth.UUID("6E400002-B5A3-F393-E0A9-E50E24DCCA9E"),
    _FLAG_WRITE,
)
_UART_SERVICE = (
    _UART_UUID,
    (_UART_TX, _UART_RX),
)

# org.bluetooth.characteristic.gap.appearance.xml
_ADV_APPEARANCE_GENERIC_COMPUTER = const(128)


class BLEUART:
    def __init__(self, ble, name="mpy-uart", rxbuf=100):
        self._ble = ble
        self._ble.active(True)
        self._ble.irq(self._irq)
        ((self._tx_handle, self._rx_handle),) = self._ble.gatts_register_services((_UART_SERVICE,))
        # Increase the size of the rx buffer and enable append mode.
        self._ble.gatts_set_buffer(self._rx_handle, rxbuf, True)
        self._connections = set()
        self._rx_buffer = bytearray()
        self._handler = None
        # Optionally add services=[_UART_UUID], but this is likely to make the payload too large.
        self._payload = advertising_payload(name=name, appearance=_ADV_APPEARANCE_GENERIC_COMPUTER)
        self._advertise()

    def irq(self, handler):
        self._handler = handler

    def _irq(self, event, data):
        # Track connections so we can send notifications.
        if event == _IRQ_CENTRAL_CONNECT:
            conn_handle, _, _ = data
            self._connections.add(conn_handle)
        elif event == _IRQ_CENTRAL_DISCONNECT:
            conn_handle, _, _ = data
            if conn_handle in self._connections:
                self._connections.remove(conn_handle)
            # Start advertising again to allow a new connection.
            self._advertise()
        elif event == _IRQ_GATTS_WRITE:
            conn_handle, value_handle = data
            if conn_handle in self._connections and value_handle == self._rx_handle:
                self._rx_buffer += self._ble.gatts_read(self._rx_handle)
                if self._handler:
                    self._handler()

    def any(self):
        return len(self._rx_buffer)

    def read(self, sz=None):
        if not sz:
            sz = len(self._rx_buffer)
        result = self._rx_buffer[0:sz]
        self._rx_buffer = self._rx_buffer[sz:]
        return result

    def write(self, data):
        for conn_handle in self._connections:
            self._ble.gatts_notify(conn_handle, self._tx_handle, data)

    def close(self):
        for conn_handle in self._connections:
            self._ble.gap_disconnect(conn_handle)
        self._connections.clear()

    def _advertise(self, interval_us=500000):
        self._ble.gap_advertise(interval_us, adv_data=self._payload)


def demo():
    import time

    ble = bluetooth.BLE()
    uart = BLEUART(ble)

    def on_rx():
        print("rx: ", uart.read().decode().strip())

    uart.irq(handler=on_rx)
    nums = [4, 8, 15, 16, 23, 42]
    i = 0

    try:
        while True:
            uart.write(str(nums[i]) + "\n")
            i = (i + 1) % len(nums)
            time.sleep_ms(1000)
    except KeyboardInterrupt:
        pass

    uart.close()

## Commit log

2022-03-26 inicio a subir el material pendiente
2022-05-08 Agregue la carpeta esquematico
2022-05-28 Cambié la ubicación de los archivos a la wiki
2022-06-06 listas de elementos
    [Regulador.kicad_sch, esp32_2.csv, esp32_2.kicad_sch]
